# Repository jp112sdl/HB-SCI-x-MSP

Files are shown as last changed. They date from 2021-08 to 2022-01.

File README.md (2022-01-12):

# HB-SCI-x-MSP

Ultra-Low-Power 1...4-fach Schließerkontakt-Interface _(basiert auf HM-SCI-3-FM mit MSP430(F2001) Kontaktüberwachung)_.

https://user-images.githubusercontent.com/18190139/149153497-77211921-73f8-495d-b231-c35b709c72b2.mp4

- Code für den MSP430: [main.c](https://github.com/jp112sdl/HB-SCI-x-MSP/blob/master/TI_MSP430/main.c)
- Code für den AVR: [MSP430State.h](https://github.com/jp112sdl/HB-SCI-x-MSP/blob/master/MSP430State.h) und [HB-SCI-x-MSP.ino](https://github.com/jp112sdl/HB-SCI-x-MSP/blob/master/HB-SCI-x-MSP.ino)
  - benötigte Libs: 
    - [Low-Power](https://github.com/rocketscream/Low-Power/)
    - [EnableInterrupt](https://github.com/GreyGnome/EnableInterrupt/)
    - [AskSinPP](https://github.com/pa-pa/AskSinPP)

#### Schaltplan
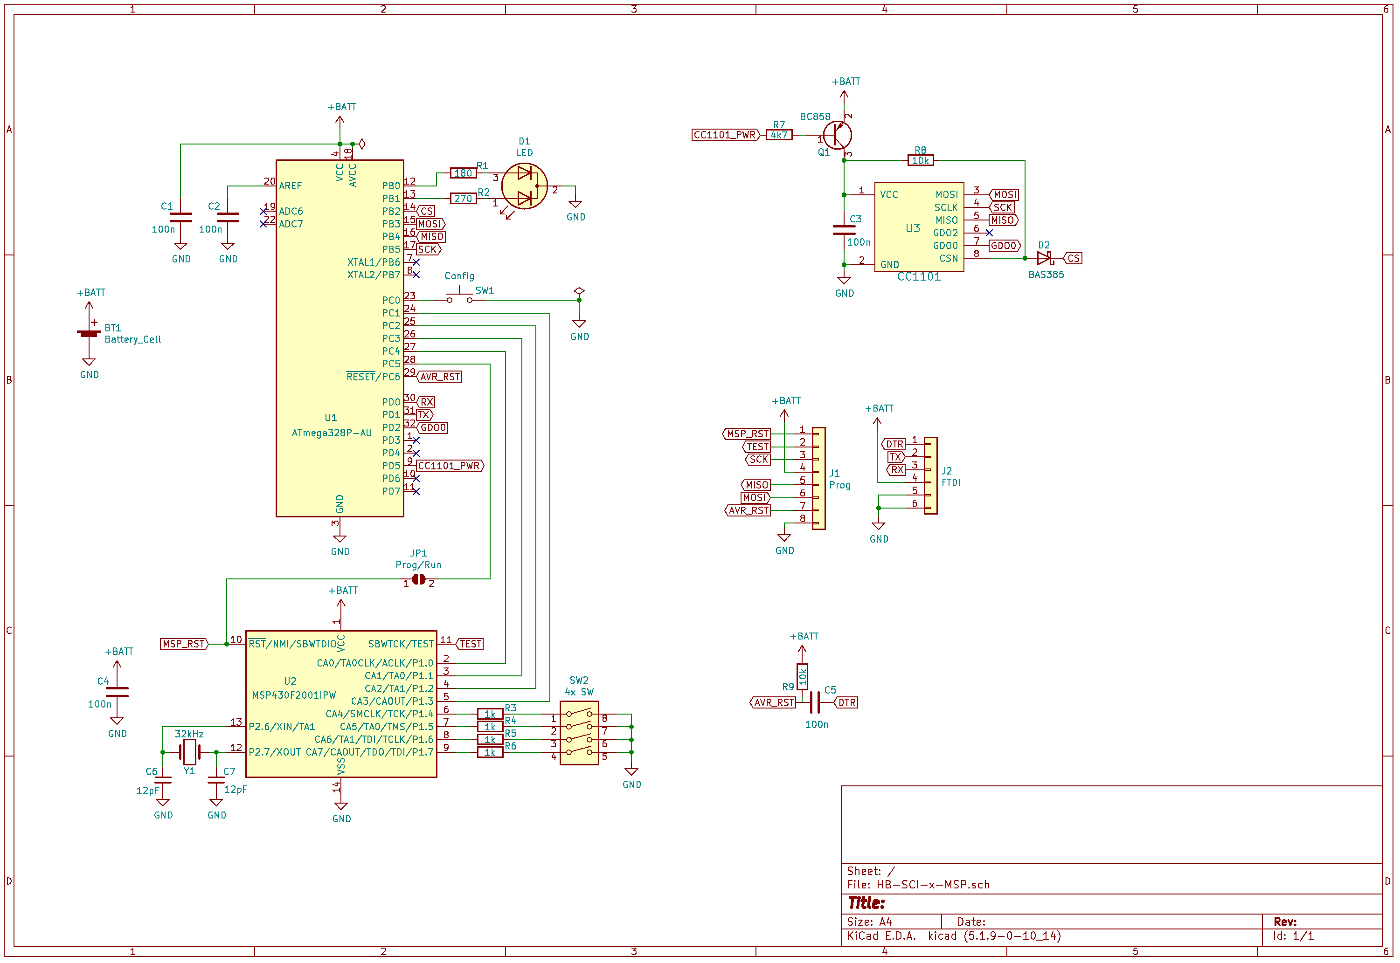
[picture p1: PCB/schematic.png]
schematic


#### Platine (57x24mm)
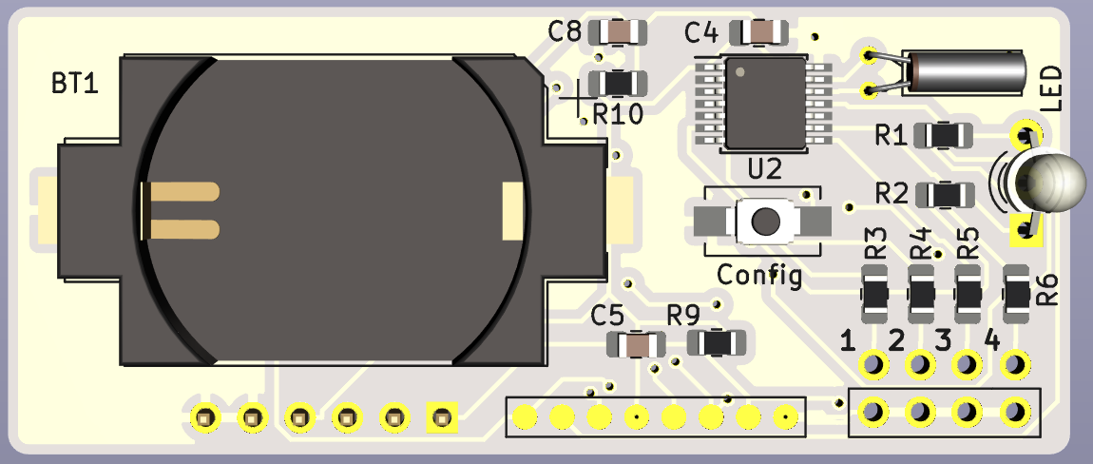
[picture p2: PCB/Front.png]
front

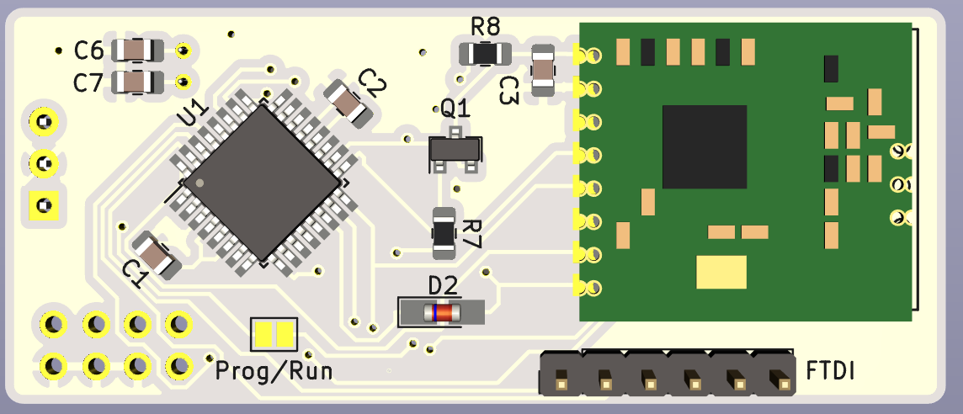
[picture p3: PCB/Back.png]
back


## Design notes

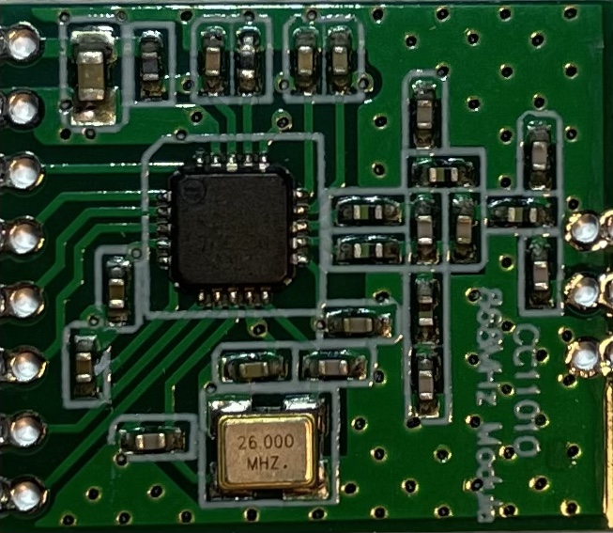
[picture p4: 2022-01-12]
Blender/CC1101.jpg

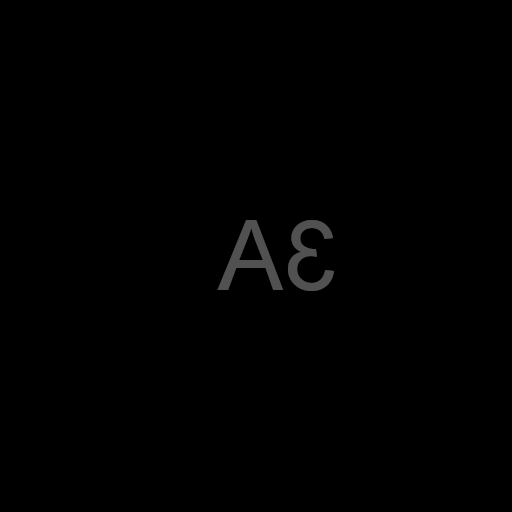
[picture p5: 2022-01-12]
Blender/3A.png

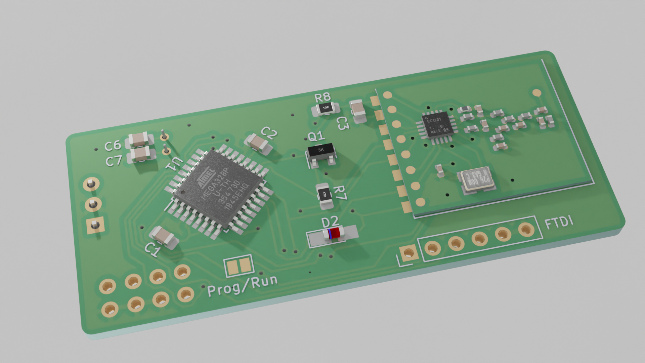
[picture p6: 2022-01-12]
PCB/3DBack.png

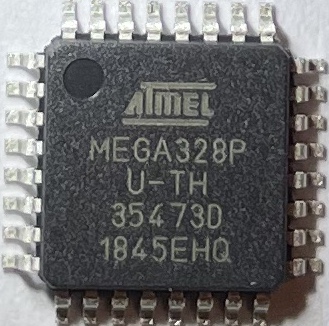
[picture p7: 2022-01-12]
Blender/ATmega328P.jpg

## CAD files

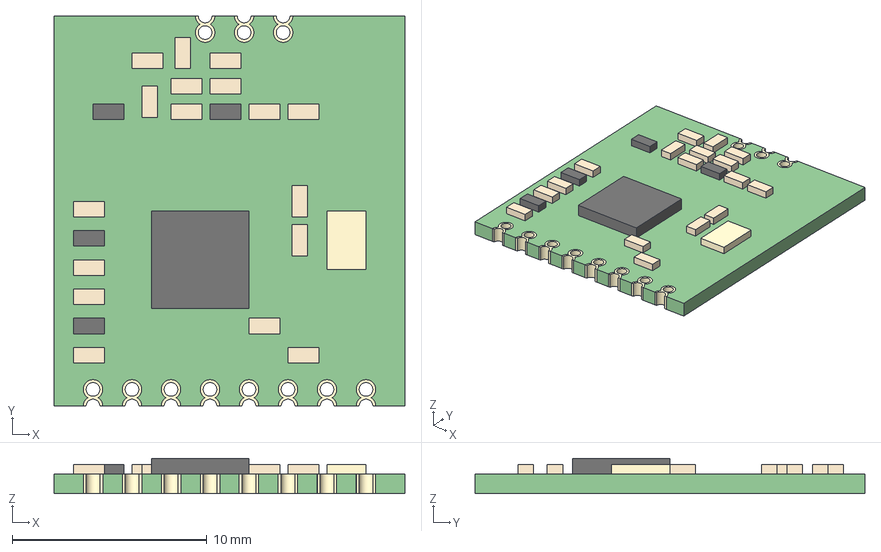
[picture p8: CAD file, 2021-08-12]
PCB/additional/CC1101_Module.step
18.0 x 20.0 x 1.80 mm
PCB
Parts
Pads

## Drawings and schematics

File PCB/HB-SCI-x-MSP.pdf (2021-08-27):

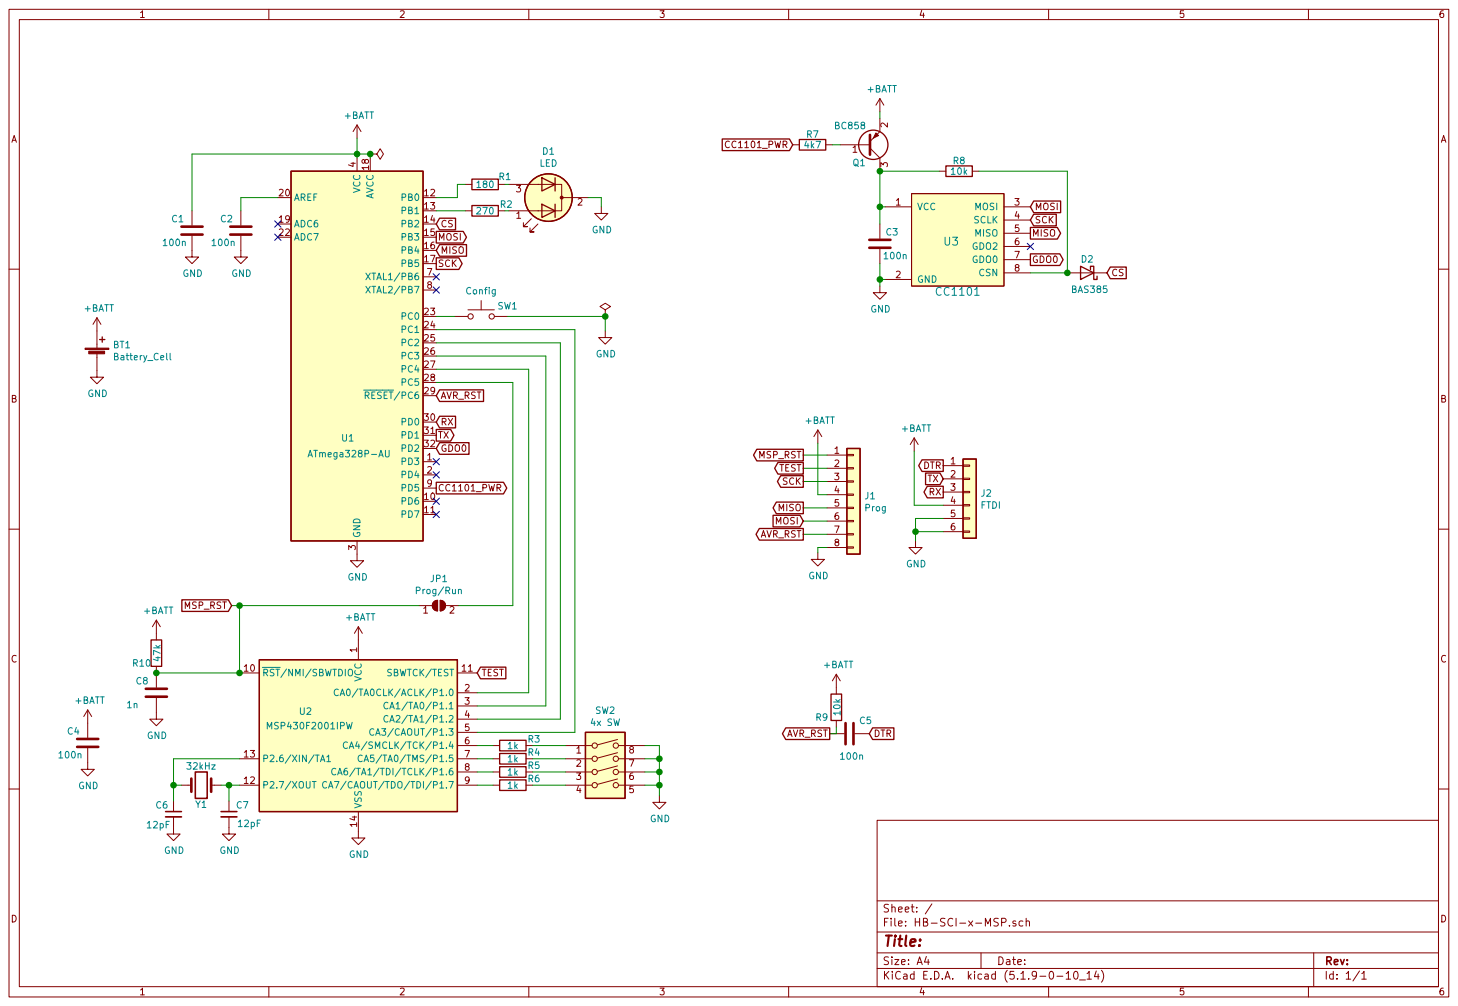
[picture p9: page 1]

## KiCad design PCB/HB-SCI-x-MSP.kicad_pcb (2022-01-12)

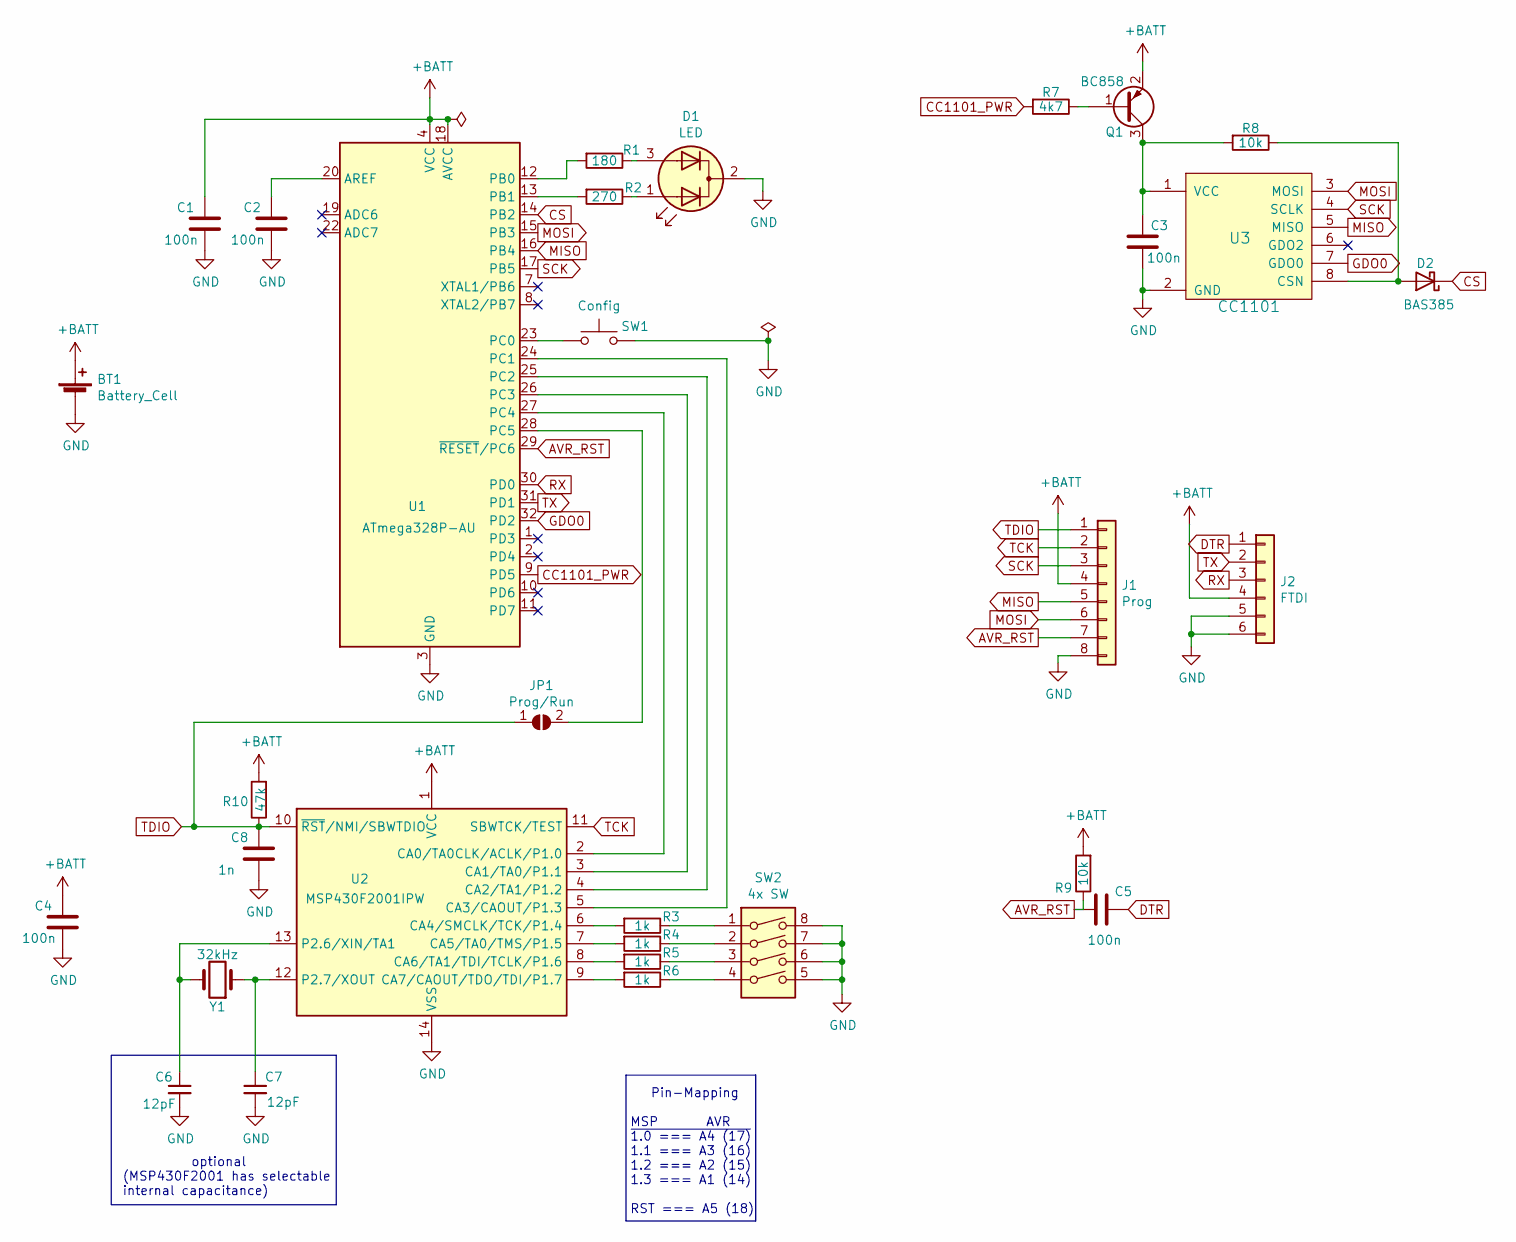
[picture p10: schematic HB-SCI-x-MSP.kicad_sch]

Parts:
BT1: Battery_Cell; BatteryHolder_Keystone_1060_1x2032
C1, C2, C3, C4, C5: 100n; C_0805_2012Metric_Pad1.15x1.40mm_HandSolder
C6, C7: 12pF; C_0805_2012Metric_Pad1.15x1.40mm_HandSolder
C8: 1n; C_0805_2012Metric_Pad1.15x1.40mm_HandSolder
D1: LED; LED_D3.0mm-3
D2: BAS385; D_MicroMELF_Hadsoldering
J1: Prog; PinHeader_1x08_P2.00mm_Vertical
J2: FTDI; PinHeader_1x06_P2.54mm_Vertical
JP1: Prog/Run; SolderJumper-2_P1.3mm_Open_Pad1.0x1.5mm
Q1: BC858; SOT-23
R1: 180; R_0805_2012Metric_Pad1.15x1.40mm_HandSolder
R2: 270; R_0805_2012Metric_Pad1.15x1.40mm_HandSolder
R3, R4, R5, R6: 1k; R_0805_2012Metric_Pad1.15x1.40mm_HandSolder
R7: 4k7; R_0805_2012Metric_Pad1.15x1.40mm_HandSolder
R8, R9: 10k; R_0805_2012Metric_Pad1.15x1.40mm_HandSolder
R10: 47k; R_0805_2012Metric_Pad1.15x1.40mm_HandSolder
SW1: Config; SW_SPST_EVQPE1
SW2: 4x SW; PinHeader_2x04_P2.54mm_Vertical
U1: ATmega328P-AU; TQFP-32_7x7mm_P0.8mm
U2: MSP430F2001IPW; TSSOP-14_4.4x5mm_P0.65mm
U3: CC1101; CC1101_Pads
Y1: 32kHz; Crystal_DS26_D2.0mm_L6.0mm_Horizontal

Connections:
+BATT: BT1.1 (+), C1.1, C4.1, J1.4, J2.4, Q1.2 (E), R9.2, R10.2, U1.4 (VCC), U1.6 (VCC), U1.18 (AVCC), U2.1 (VCC)
AVR_RST: C5.2, J1.7, R9.1, U1.29 (~RESET/PC6)
CC1101_PWR: R7.2, U1.9 (PD5)
CS: D2.1 (K), U1.14 (PB2)
DTR: C5.1, J2.1
GDO0: U1.32 (PD2), U3.7 (GDO0)
GND: BT1.2 (-), C1.2, C2.2, C3.2, C4.2, C6.2, C7.2, C8.2, D1.2 (K), J1.8, J2.5, J2.6, SW1.2, SW2.5, SW2.6, SW2.7, SW2.8, U1.3 (GND), U1.5 (GND), U1.21 (GND), U2.14 (VSS), U3.2 (GND)
MISO: J1.5, U1.16 (PB4), U3.5 (MISO)
MOSI: J1.6, U1.15 (PB3), U3.3 (MOSI)
unnamed: C2.1, U1.20 (AREF)
unnamed: C3.1, Q1.3 (C), R8.2, U3.1 (VCC)
unnamed: C6.1, U2.13 (P2.6/XIN/TA1), Y1.2
unnamed: C7.1, U2.12 (P2.7/XOUT), Y1.1
unnamed: D1.1 (A1), R2.1
unnamed: D1.3 (A2), R1.1
unnamed: D2.2 (A), R8.1, U3.8 (CSN)
unnamed: JP1.2 (B), U1.28 (PC5)
unnamed: Q1.1 (B), R7.1
unnamed: R1.2, U1.12 (PB0)
unnamed: R2.2, U1.13 (PB1)
unnamed: R3.1, SW2.1
unnamed: R3.2, U2.6 (CA4/SMCLK/TCK/P1.4)
unnamed: R4.1, SW2.2
unnamed: R4.2, U2.7 (CA5/TA0/TMS/P1.5)
unnamed: R5.1, SW2.3
unnamed: R5.2, U2.8 (CA6/TA1/TDI/TCLK/P1.6)
unnamed: R6.1, SW2.4
unnamed: R6.2, U2.9 (CA7/CAOUT/TDO/TDI/P1.7)
unnamed: SW1.1, U1.23 (PC0)
unnamed: U1.24 (PC1), U2.5 (CA3/CAOUT/P1.3)
unnamed: U1.25 (PC2), U2.4 (CA2/TA1/P1.2)
unnamed: U1.26 (PC3), U2.3 (CA1/TA0/P1.1)
unnamed: U1.27 (PC4), U2.2 (CA0/TA0CLK/ACLK/P1.0)
RX: J2.3, U1.30 (PD0)
SCK: J1.3, U1.17 (PB5), U3.4 (SCLK)
TCK: J1.2, U2.11 (SBWTCK/TEST)
TDIO: C8.1, J1.1, JP1.1 (A), R10.1, U2.10 (~RST/NMI/SBWTDIO)
TX: J2.2, U1.31 (PD1)

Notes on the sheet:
Pin-Mapping MSP AVR ~{1.0 === A4 (17)} 1.1 === A3 (16) 1.2 === A2 (15) 1.3 === A1 (14) RST === A5 (18)
optional (MSP430F2001 has selectable internal capacitance)

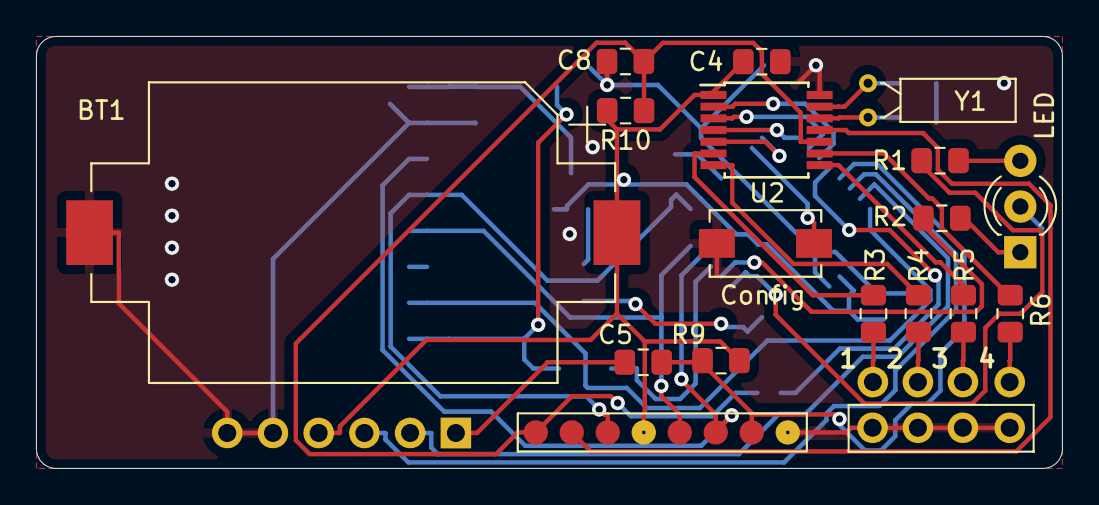
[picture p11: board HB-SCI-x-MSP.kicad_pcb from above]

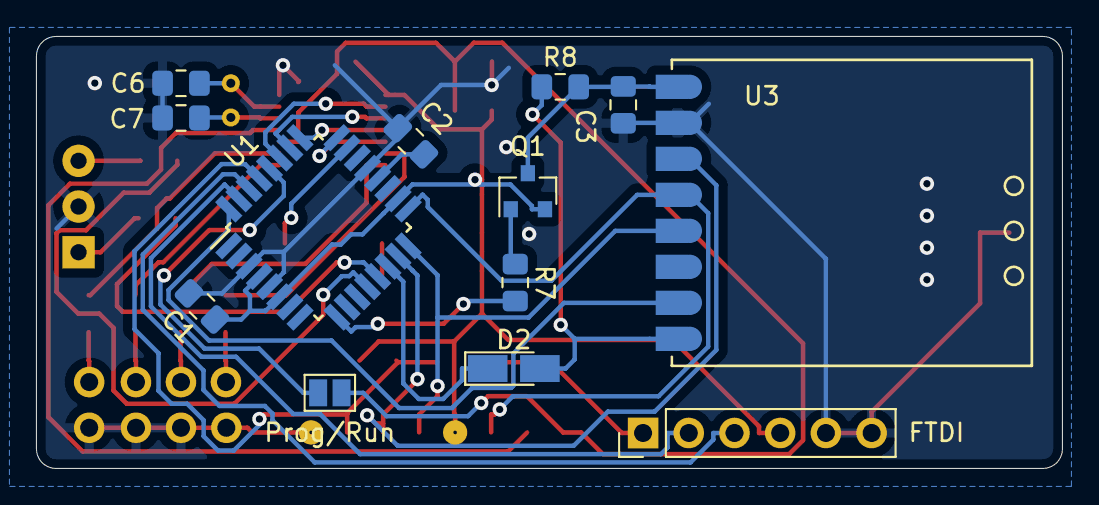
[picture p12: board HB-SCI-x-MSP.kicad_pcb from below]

Board: 2 copper layers, 57.0 x 24.0 mm, 31 parts (13 on the bottom side), 38 nets.

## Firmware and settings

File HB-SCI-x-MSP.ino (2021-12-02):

//- -----------------------------------------------------------------------------------------------------------------------
// AskSin++
// 2016-10-31 papa Creative Commons - http://creativecommons.org/licenses/by-nc-sa/3.0/de/
// 2021-08-11 jp112sdl Creative Commons - http://creativecommons.org/licenses/by-nc-sa/3.0/de/
//- -----------------------------------------------------------------------------------------------------------------------
// ci-test=yes board=328p aes=no

// define this to read the device id, serial and device type from bootloader section
// #define USE_OTA_BOOTLOADER

#define SIMPLE_CC1101_INIT
#define NO_RTC
#define NO_CRC
#define NDEBUG
#define SENSOR_ONLY

#define EI_ATTINY24
#define EI_NOTPORTA
#define EI_NOTPORTB
#define EI_NOTEXTERNAL
#include <EnableInterrupt.h>
#include <LowPower.h>
#include <AskSinPP.h>
#include <Register.h>
#include <Button.h>

#define I_WAKEUP A4
#define I_DATA   A3
#define O_AWAKE  A2
#define O_CLK    A1
#define O_RST    A5

#define NUM_CHANNELS       4

#include "MSP430State.h"

using namespace as;


#define LED_PIN           8
#define LED_PIN2          9
#define CONFIG_BUTTON_PIN A0

#define CC1101_PWR        5

#define PEERS_PER_CHANNEL 10
#define POWEROFF_DELAY_MILLIS 3500

const struct DeviceInfo PROGMEM devinfo = {
  {0x00, 0x5F, 0x01},     // Device ID
  "JPSCI30012",           // Device Serial
  {0x00, 0x5F},           // Device Model
  0x22,                   // Firmware Version
  as::DeviceType::Swi,    // Device Type
  {0x00, 0x00}            // Info Bytes
};

typedef AvrSPI<10, 11, 12, 13> SPIType;
typedef Radio<SPIType, 2, CC1101_PWR> RadioType;
typedef DualStatusLed<LED_PIN, LED_PIN2> LedType;
typedef AskSin<LedType, IrqInternalBatt, RadioType> Hal;

DEFREGISTER(Reg0, DREG_CYCLICINFOMSG, MASTERID_REGS, DREG_TRANSMITTRYMAX)
class SCList0 : public RegList0<Reg0> {
  public:
    SCList0(uint16_t addr) : RegList0<Reg0>(addr) {}
    void defaults () {
      clear();
      cycleInfoMsg(true);
      transmitDevTryMax(6);
    }
};

DEFREGISTER(Reg1, CREG_AES_ACTIVE, CREG_MSGFORPOS, CREG_EVENTDELAYTIME, CREG_TRANSMITTRYMAX)
class SCList1 : public RegList1<Reg1> {
  public:
    SCList1 (uint16_t addr) : RegList1<Reg1>(addr) {}
    void defaults () {
      clear();
      msgForPosA(1); // CLOSED
      msgForPosB(2); // OPEN
      //aesActive(false);
      eventDelaytime(0);
      transmitTryMax(6);
    }
};

typedef MSPStateChannel<Hal, SCList0, SCList1, DefList4, PEERS_PER_CHANNEL> ChannelType;
typedef StateDevice<Hal, ChannelType, NUM_CHANNELS, SCList0> SCType;

Hal hal;
SCType sdev(devinfo, 0x20);
ConfigButton<SCType> cfgBtn(sdev);

void setup () {
  DINIT(57600, ASKSIN_PLUS_PLUS_IDENTIFIER);
  sdev.init(hal);

  hal.battery.init();
  hal.battery.low(21);
  hal.battery.critical(19);

  while (hal.battery.current() == 0);
  buttonISR(cfgBtn, CONFIG_BUTTON_PIN);
  sdev.initDone();

  contactISR(sdev, I_WAKEUP);
}

class PowerOffAlarm : public Alarm {
  private:
    bool    timerActive;
  public:
    PowerOffAlarm () : Alarm(0), timerActive(false) {}
    virtual ~PowerOffAlarm () {}

    void activateTimer(bool en) {
      if (en == true && timerActive == false) {
        sysclock.cancel(*this);
        set(millis2ticks(POWEROFF_DELAY_MILLIS));
        sysclock.add(*this);
      } else if (en == false) {
        sysclock.cancel(*this);
      }
      timerActive = en;
    }

    virtual void trigger(__attribute__((unused)) AlarmClock& clock) {
      powerOff();
    }

    void powerOff() {
      sdev.check();  //re-check before sleep
      hal.led.ledOff();
      hal.radio.setIdle();
      DPRINTLN("DEEPSLEEP");_delay_ms(200);
      LowPower.powerDown(SLEEP_FOREVER, ADC_OFF, BOD_OFF);
    }

} pwrOffAlarm;

bool isAnyChannelActive() {
  for (uint8_t i = 0; i < NUM_CHANNELS; i++) {
    if (sdev.channel(i+1).isActive()) {
      return true;
    }
  }
  return false;
}

void loop() {
  bool worked = hal.runready();
  bool poll = sdev.pollRadio();
  bool act  = isAnyChannelActive();

  if (act == true && worked == false && poll == false) {
    hal.sleep();
  } else {
    pwrOffAlarm.activateTimer(act == false && hal.activity.stayAwake() == false && worked == false && poll == false );
  }
}

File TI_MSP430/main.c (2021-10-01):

// 2021-08-11 jp112sdl Creative Commons - CC-BY-NC-SA http://creativecommons.org/licenses/by-nc-sa/4.0/de/

#include <msp430.h>
#include <stdint.h>
#include <stdbool.h>

#define OUT_AVR_WAKE_PIN     BIT0  //output, wake up the AVR
#define OUT_AVR_DATA         BIT1  //output, send data to the AVR
#define IN_AVR_IS_AWAKE_PIN  BIT2  //input, to check, if the AVR is not sleeping
#define IN_AVR_CLK_PIN       BIT3  //input, the clock for bitwise data sending on OUT_AVR_DATA pin
#define IN_SW1_PIN           BIT4  //input, contact to monitor
#define IN_SW2_PIN           BIT5  //input, contact to monitor
#define IN_SW3_PIN           BIT6  //input, contact to monitor
#define IN_SW4_PIN           BIT7  //input, contact to monitor

#define CYCLE_TIME           86400 * 4UL // every 24 hours (seconds * 4 -> 250ms tick interval)

uint32_t cycleCount      = CYCLE_TIME;
uint8_t  contactState    = 0;
uint8_t  lastContactState= 0xAA;

void sleep_1_9ms(uint8_t cnt) { uint8_t i; for (i = cnt; i > 0; i--) { WDTCTL = WDT_ADLY_1_9; __bis_SR_register(LPM3_bits + GIE); } }
void sleep_16ms (uint8_t cnt) { uint8_t i; for (i = cnt; i > 0; i--) { WDTCTL = WDT_ADLY_16;  __bis_SR_register(LPM3_bits + GIE); } }
void sleep_250ms(uint8_t cnt) { uint8_t i; for (i = cnt; i > 0; i--) { WDTCTL = WDT_ADLY_250; __bis_SR_register(LPM3_bits + GIE); } }

bool isAVRAwake()     { return ( P1IN & IN_AVR_IS_AWAKE_PIN ); }
bool AVRClockStrobe() { return ( P1IN & IN_AVR_CLK_PIN      ); }

void configurePins() {
    P1DIR &= ~IN_AVR_IS_AWAKE_PIN;
    P1DIR &= ~IN_AVR_CLK_PIN;
    P1DIR &= ~IN_SW1_PIN;
    P1DIR &= ~IN_SW2_PIN;
    P1DIR &= ~IN_SW3_PIN;
    P1DIR &= ~IN_SW4_PIN;
    P1REN |= IN_SW1_PIN | IN_SW2_PIN | IN_SW3_PIN | IN_SW4_PIN;
    P1OUT |= IN_SW1_PIN | IN_SW2_PIN | IN_SW3_PIN | IN_SW4_PIN;

    P1IE  |=  IN_AVR_IS_AWAKE_PIN;
    P1IES &= ~IN_AVR_IS_AWAKE_PIN;
    P1IFG &= ~IN_AVR_IS_AWAKE_PIN;
}

void idlePins() {
    P1DIR = 0xFF;    /*P1REN = 0;*/    P1OUT = 0;
    P2DIR = 0xFF;    /*P2REN = 0;*/    P2OUT = 0;
#ifdef __MSP430_HAS_PORT3_R__
    P3DIR = 0xFF;    /*P3REN = 0;*/    P3OUT = 0;
#endif
}

uint8_t readPins() {
  sleep_1_9ms(2); // wait ~ 2ms
  uint8_t result = 0;
  if (P1IN & IN_SW1_PIN) result |= 0b00000001;
  if (P1IN & IN_SW2_PIN) result |= 0b00000010;
  if (P1IN & IN_SW3_PIN) result |= 0b00000100;
  if (P1IN & IN_SW4_PIN) result |= 0b00001000;
  return result;
}

void wakeupAVR() {
    P1OUT  |=  OUT_AVR_WAKE_PIN;
    sleep_16ms(1);
    P1OUT  &= ~OUT_AVR_WAKE_PIN;
}

int main(void) {
  BCSCTL1 |= DIVA_0;        // ACLK/1
  //BCSCTL3 |= XCAP_2;        // 9pF load capacitor
  WDTCTL   = WDT_ADLY_250;  // WDT 250ms interval timer
  IE1     |= WDTIE;         // Enable WDT interrupt

  idlePins();

  sleep_250ms(8);           //wait 2 seconds after first init or reset

  while(1) {
    cycleCount--;
    configurePins();
    contactState  = 0;
    contactState |= readPins();

    if ((contactState != lastContactState) || (cycleCount == 0)) {
      lastContactState = contactState;
      if (cycleCount == 0) contactState |= 0b10000000;

      cycleCount          = CYCLE_TIME;
      bool lastStrobe     = false;
      uint8_t  clk_count  = 8;
      uint16_t exit_count = 5;  //prevent endless loop if AVR does not respond

      while (!isAVRAwake() && exit_count > 0) {
        sleep_1_9ms(2);
        wakeupAVR();
        exit_count--;
      }

      exit_count = 1000;
      while (isAVRAwake() && exit_count > 0 && clk_count > 0) {
        exit_count--;
        bool strobe = AVRClockStrobe();
        if (strobe != lastStrobe && strobe == true) { clk_count--; } //on rising edge
        lastStrobe = strobe;
             if (clk_count == 7) {  if (contactState & 0b00000001)  { P1OUT  |=  OUT_AVR_DATA; } else { P1OUT  &= ~OUT_AVR_DATA; } }
        else if (clk_count == 6) {  if (contactState & 0b00000010)  { P1OUT  |=  OUT_AVR_DATA; } else { P1OUT  &= ~OUT_AVR_DATA; } }
        else if (clk_count == 5) {  if (contactState & 0b00000100)  { P1OUT  |=  OUT_AVR_DATA; } else { P1OUT  &= ~OUT_AVR_DATA; } }
        else if (clk_count == 4) {  if (contactState & 0b00001000)  { P1OUT  |=  OUT_AVR_DATA; } else { P1OUT  &= ~OUT_AVR_DATA; } }
        else if (clk_count == 3) {  if (contactState & 0b00010000)  { P1OUT  |=  OUT_AVR_DATA; } else { P1OUT  &= ~OUT_AVR_DATA; } }
        else if (clk_count == 2) {  if (contactState & 0b00100000)  { P1OUT  |=  OUT_AVR_DATA; } else { P1OUT  &= ~OUT_AVR_DATA; } }
        else if (clk_count == 1) {  if (contactState & 0b01000000)  { P1OUT  |=  OUT_AVR_DATA; } else { P1OUT  &= ~OUT_AVR_DATA; } }
        else if (clk_count == 0) {  if (contactState & 0b10000000)  { P1OUT  |=  OUT_AVR_DATA; } else { P1OUT  &= ~OUT_AVR_DATA; } }
        else                                                                                          { P1OUT  &= ~OUT_AVR_DATA; }
      }

    } else {
      idlePins();
      sleep_250ms(2);
    }
  }

}

#pragma vector=WDT_VECTOR
__interrupt void watchdog_timer (void) { __bic_SR_register_on_exit(LPM3_bits + GIE); }

#pragma vector=PORT1_VECTOR
__interrupt void Port_1(void){
  P1IFG &= ~IN_AVR_IS_AWAKE_PIN;
  lastContactState = 0xAA;
}

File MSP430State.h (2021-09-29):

//- -----------------------------------------------------------------------------------------------------------------------
// AskSin++
// 2017-10-19 papa Creative Commons - http://creativecommons.org/licenses/by-nc-sa/3.0/de/
// 2020-01-30 jp112sdl Creative Commons - http://creativecommons.org/licenses/by-nc-sa/3.0/de/
//- -----------------------------------------------------------------------------------------------------------------------

#ifndef __MSP430CONTACTSTATE_H__
#define __MSP430CONTACTSTATE_H__

#include <MultiChannelDevice.h>

enum State { NoPos = 0, PosA, PosB };

#define STROBE_DLY  1500
#define READ_COUNT  8

namespace as {

template <class HALTYPE, class List0Type, class List1Type, class List4Type, int PEERCOUNT>
class MSPStateChannel : public Channel<HALTYPE, List1Type, EmptyList, List4Type, PEERCOUNT, List0Type> {

   class EventSender : public Alarm {
      public:
        MSPStateChannel& channel;
        uint8_t count, state;

        EventSender (MSPStateChannel& c) : Alarm(0), channel(c), count(0), state(0xff) {}
        virtual ~EventSender () {}
        virtual void trigger (__attribute__ ((unused)) AlarmClock& clock) {
          SensorEventMsg& msg = (SensorEventMsg&)channel.device().message();
          msg.init(channel.device().nextcount(), channel.number(), count++, state, channel.device().battery().low());
          channel.device().sendPeerEvent(msg, channel);
        }
    };
   EventSender sender;

  public:
    typedef Channel<HALTYPE, List1Type, EmptyList, List4Type, PEERCOUNT, List0Type> BaseChannel;

    MSPStateChannel () : BaseChannel(), sender(*this) {}
    virtual ~MSPStateChannel () {}

    void setup(Device<HALTYPE, List0Type>* dev, uint8_t number, uint16_t addr) {
      BaseChannel::setup(dev, number, addr);
    }

    void sendState (uint8_t posi) {
      uint8_t msg = 0;
      switch ( posi ) {
        case State::PosA:
          msg = this->getList1().msgForPosA();
          break;
        case State::PosB:
          msg = this->getList1().msgForPosB();
          break;
        default:
          break;
      }

      uint8_t newstate = sender.state;
      if ( msg == 1) newstate = 0;
      else if ( msg == 2) newstate = 200;

      if (newstate != sender.state) {
        uint8_t delay = this->getList1().eventDelaytime();
        sender.state = newstate;
        sysclock.cancel(sender);
        if ( delay == 0 ) {
          sender.trigger(sysclock);
        }
        else {
          sender.set(AskSinBase::byteTimeCvtSeconds(delay));
          sysclock.add(sender);
        }
      }
    }

    uint8_t status () const {
      return sender.state;
    }

    bool isActive() {
      return sender.active();
    }

    uint8_t flags () const {
      uint8_t flags =  0x00;
      flags |= this->device().battery().low() ? 0x80 : 0x00;
      return flags;
    }

};

template<class HalType, class ChannelType, int ChannelCount, class List0Type>
class StateDevice : public MultiChannelDevice<HalType, ChannelType, ChannelCount, List0Type> {

  class CheckAlarm : public Alarm {
    public:
    StateDevice& sd;
      CheckAlarm (StateDevice& _sd) : Alarm(0), sd(_sd) {}
      virtual ~CheckAlarm () {}
      virtual void trigger(__attribute__((unused)) AlarmClock& clock) {
        sd.check();
      }
  };

  private:
    bool mspRead() {
      digitalWrite(O_CLK, HIGH);
      _delay_us(STROBE_DLY);
      bool res = digitalRead(I_DATA);
      digitalWrite(O_CLK, LOW);
      _delay_us(STROBE_DLY);
      return res;
  }
  private:
    volatile bool canInterrupt;
    bool cycleEnabled;

  protected:
    CheckAlarm ca;
  public:
    typedef MultiChannelDevice<HalType, ChannelType, ChannelCount, List0Type> DevType;
    StateDevice(const DeviceInfo& info, uint16_t addr) : DevType(info, addr), canInterrupt(true), cycleEnabled(true), ca(*this) {}
    virtual ~StateDevice () {}


    void irq() {
      sysclock.cancel(ca);
      if (canInterrupt) {
        sysclock.add(ca);
      }
    }

    void resetMSP() {
      pinMode(O_RST, OUTPUT);
      digitalWrite(O_RST, LOW);
      _delay_ms(100);
      pinMode(O_RST, INPUT);
    }

    void initPins() {
      pinMode(I_WAKEUP, INPUT );
      pinMode(I_DATA  , INPUT );
      pinMode(O_RST,    INPUT ); //init as high impedance input first
      pinMode(O_CLK   , OUTPUT);
      pinMode(O_AWAKE , OUTPUT);
      resetMSP();
    }

    void check() {
      if (canInterrupt == true) {
        digitalWrite(O_AWAKE, HIGH);
        _delay_ms(2);
        canInterrupt = false;
        uint8_t mspState = 0;

        for (uint8_t i = 0; i < READ_COUNT; i++) {
          while (digitalRead(I_WAKEUP) == HIGH);
          if (mspRead()) bitSet(mspState, i);
        }

        digitalWrite(O_AWAKE, LOW);

        delay(20);

        for (uint8_t i = 0 ; i< NUM_CHANNELS;i++) {
          this->channel(i+1).sendState(mspState & 1 << i ? State::PosB : State::PosA);
        }

        if ( (mspState & 0b10000000) && cycleEnabled) {
          DPRINTLN("send cyclic");
          for (uint8_t i = 0 ; i< NUM_CHANNELS;i++) {
            this->channel(i+1).changed(true);
          }
        }

        canInterrupt = true;
      }
    }

    virtual void configChanged () {
      cycleEnabled = this->getList0().cycleInfoMsg();
    }
};


#define contactISR(dev,pin) class __##pin##ISRHandler { \
    public: \
      static void isr () { dev.irq(); } \
  }; \
    dev.initPins(); \
    enableInterrupt(pin,__##pin##ISRHandler::isr,RISING);
}

#endif

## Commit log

2021-08-12 add PCB
    [CC1101_Module.step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]
2021-08-12 add pcb images
    [HB-SCI-x-MSP.kicad_pcb]
2021-08-12 add schematic image
2021-08-19 update PCB
    [HB-SCI-x-MSP-B_Cu.gbr, HB-SCI-x-MSP-B_Mask.gbr, HB-SCI-x-MSP-B_Paste.gbr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]
2021-08-19 stay awake a little bit longer to guarantee long config button press for RESET
    [HB-SCI-x-MSP.ino]
2021-08-27 modified pins according to pcb layout
2021-09-29 wake up by interrupt from AVR
2021-09-29 final check for pin changes before going to sleep
2021-11-30 update Kicad 6
    [HB-SCI-x-MSP.kicad_pcb, HB-SCI-x-MSP.kicad_sch]
2022-01-12 update kicad
    [HB-SCI-x-MSP.kicad_pcb, HB-SCI-x-MSP.kicad_sch]
